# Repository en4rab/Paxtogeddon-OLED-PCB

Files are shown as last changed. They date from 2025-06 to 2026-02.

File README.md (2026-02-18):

# Paxtogeddon-OLED-PCB
### Hardware files for the Paxtogeddon reader with OLED display

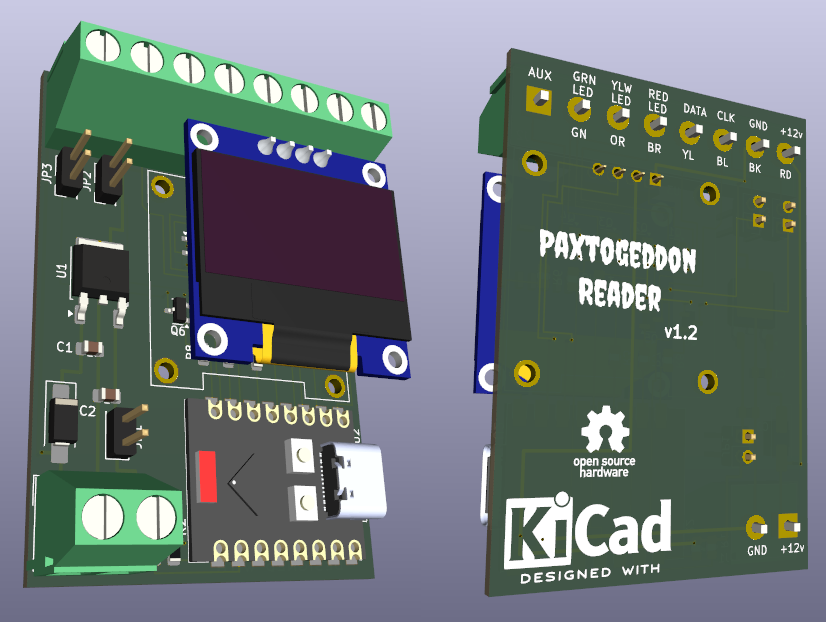
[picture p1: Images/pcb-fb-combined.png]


### kicad

The kicad directory contains the kicad project files to make a PCB for the Paxtogeddon reader. This was a project to learn Kicad and PCB design so set your expectations accordingly! If you just want to make one Paxtogeddon reader to use then you might find using 00Waz's [protoboard design](https://github.com/00Waz/Paxtogeddon-Reader) quicker and easier than ordering pcb's and smt parts from China.

### gerbers

The gerbers directory contains the gerbers for the v1.2 board and a zip file paxtogeddon-gerbers_v1_2.zip which is the zip file uploaded to JLC for manufacture of the PCB's. 

### case

The case directory contains the STL files and parts list for the 3D printed case to suit an Anker 525, 325 or 313 power bank.

### Firmware

This uses mostly the same code written by Daniel as the [board by 00Waz](https://github.com/00Waz/Paxtogeddon-Reader) with some additions to write to an OLED display. However the pin assignments are different and the pins to playback a card are now the same as those used to sniff so the associated headers and transistors can be left off. If this ever gets another revision of the pcb they will be removed. The PaxtogeddonReaderV1 directory contains the first attempt at adding an OLED, the additions were done by en4rab so any mistakes and poor code are my fault and not Daniels!  
[PaxtogeddonReaderV2.2](firmware/PaxtogeddonReaderV2_2) contains Daniel's improved version 2.2 code which supports both this PCB version and the protoboard design by Waz. It uses custom cards to configure the reader. Information on how to rewrite Paxton cards to use as the config cards can be found in [MAKE-CARDS.md](firmware/MAKE-CARDS.md)
This firmware now supports a second esp module connected to the paxtogeddon aux pin to trigger a cheap fitness band to vibrate when a card is read and new with v2.2 support for the paxton hand free interface and hands free fobs.

### Schematic

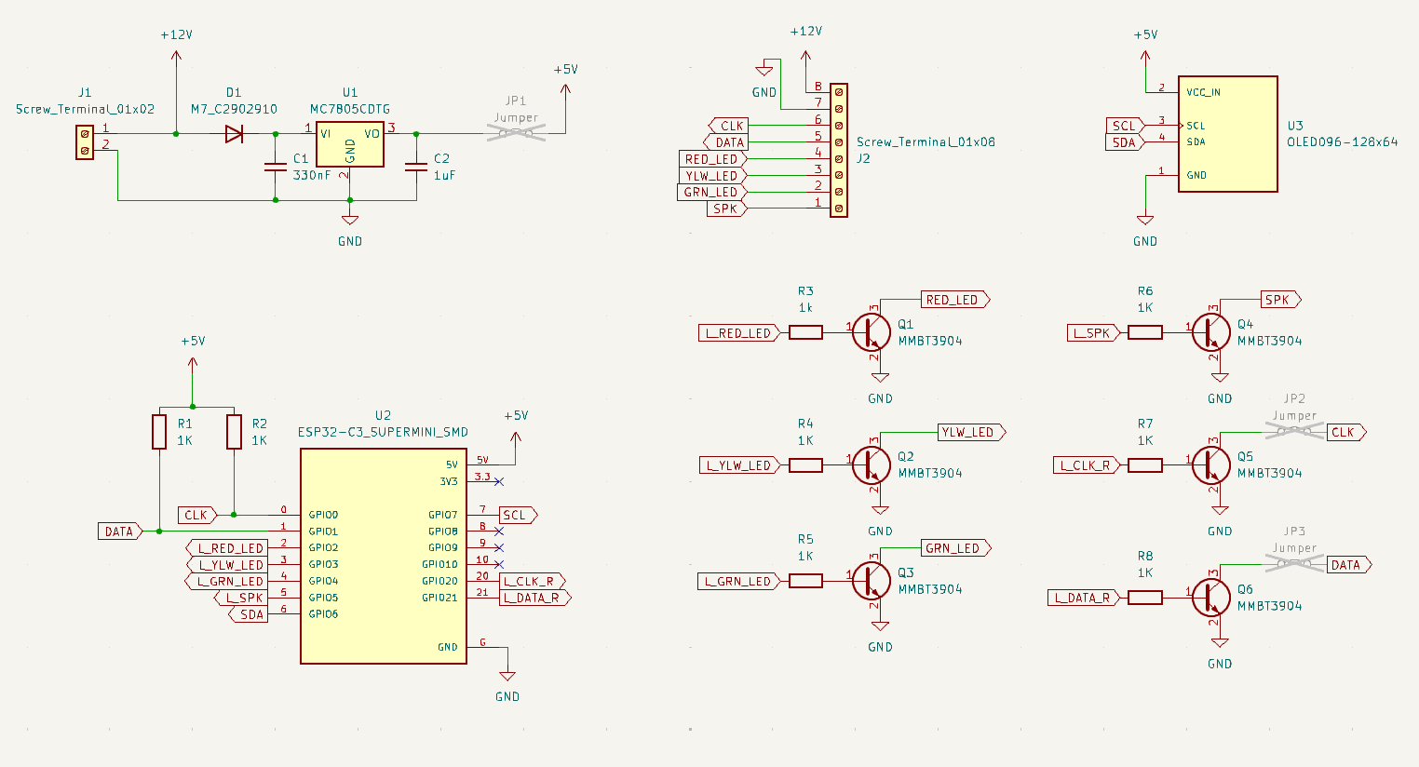
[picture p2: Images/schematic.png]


### Building the PCB
#### Assembly

Assembly is fairly straightforward. When soldering the 4 pin female header for the OLED it is easier to align it if you attach the brass standoffs to an OLED, put the header on the OLED pins then use it as a jig to hold the header in position while you solder it.

The jumper JP1 was for development to allow the 5v to be separated from the ESP32 so the Paxton reader could be powered by 12v while the esp was powered by usb for debugging. In normal use it should be connected.

JP2 and JP3 were to disconnect the card playback pins if that was not needed. In the latest firmware are unused and should be left disconnected.

Once the PCB has been soldered and cleaned use the Halnziye HY910 thermal glue to stick a small aluminium heatsink to the 7805 regulator. Initial tests without a heatsink had the regulator at about 89C adding a small heatsink lowered this to about 75C its a bit of a bodge but it seems to be working ok.

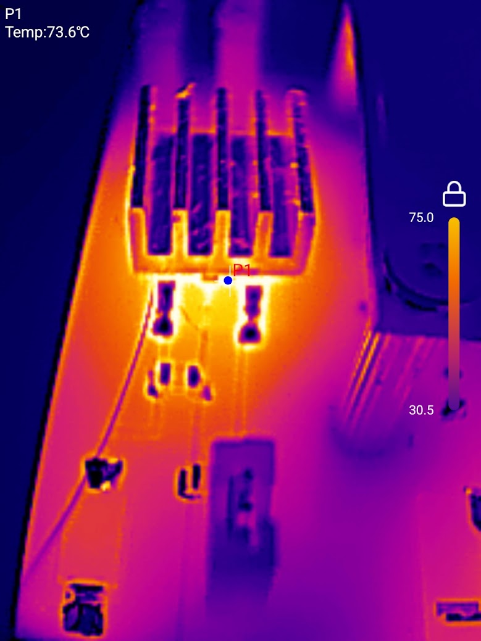
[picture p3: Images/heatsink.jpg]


#### Parts used 

This is a list of the parts used. They are not necessarily the best source and if you are being organised you could probably source everything in one order from Mouser/RS/Farnell but the links given are what was used. the 8 way screw terminal was 2x4 way terminals as they were easier to source.

| Reference | Value | Footprint | Link | Price |
| --- | --- | --- | --- | --- |
| C1 | 330nF 50v | 0805 | https://www.aliexpress.com/item/1005008635911110.html | £12.59 per 2000 |
| C2 | 1uF 16v | 0805 | https://www.aliexpress.com/item/33052613891.html | £0.88 per 100 |
| D1 | M7 (1N4007) | A-SMA | https://www.ebay.co.uk/itm/374441259098 | £4.66 per 100 |
| J1 | Screw_Terminal_01x02 | | https://www.aliexpress.com/item/1005003556955422.html | £4 per 50 |
| J2 | 2x Screw_Terminal_01x04 | | https://www.aliexpress.com/item/1005003556955422.html | £7.55 per 50 |
| JP1,JP2,JP3 | Jumper | | https://www.aliexpress.com/item/32853010777.html | £0.41 per 50 |
| Q1,Q2,Q3,<br />Q4,Q5,Q6 | MMBT3904 | SOT-23 | https://www.aliexpress.com/item/1005006991695298.html | £6.69 per 3000  |
| R1,R2,R3,R4,<br />R5,R6,R7,R8 | 1K 1/4W | 0805 | https://www.aliexpress.com/item/1005006786740896.html | £5.80 per 5000  |
| U1 | MC7805CDTG | TO-252-3  | https://www.aliexpress.com/item/1005007322548974.html | £1.16 per 5 |
| U2 | ESP32-C3 Supermini | | https://www.aliexpress.com/item/1005006056663228.html | £1.89 |
| U3 | OLED096-128x64 | | https://www.aliexpress.com/item/1005006700885056.html | £1.74 |
| | 4 pin socket female | | https://www.ebay.co.uk/itm/192175350096 | £3.89 per 100 |
| | Heatsink | 9x9x5mm | https://www.aliexpress.com/item/1005004453446730.html | £4.59 per 50 |
| | Halnziye HY910<br />Thermal glue | 5g | https://www.ebay.co.uk/itm/256626403139 | £2.75 |
| | 11mm M2 brass standoffs and M2 screws to mount the OLED are listed with the case hardware in the case directory | | | |

> [!CAUTION]
> The ESP32 supermini module has a near identical clone that is badly made and has problems with the wifi, this site describes the issue and how to spot the bad boards [https://roryhay.es/blog/esp32-c3-super-mini-flaw](https://roryhay.es/blog/esp32-c3-super-mini-flaw) TL;DR avoid the boards with "mouse bites" to separate the boards. If you do get a bad board and wifi doesn't work one test board worked better with a small blob of blu-tak stuck on the antenna simulating a finger touching the antenna. Guess how I figured that one out 🤣

> [!WARNING]  
> 0.96" OLED modules come in at least 4 different variants the most significant difference being the order of the pins. This board uses a 4 pin module with GND on the left most pin. They also differ in size and hole spacing. look for a seller showing a board with GME12864-11-12-13 on the back as shown.
>
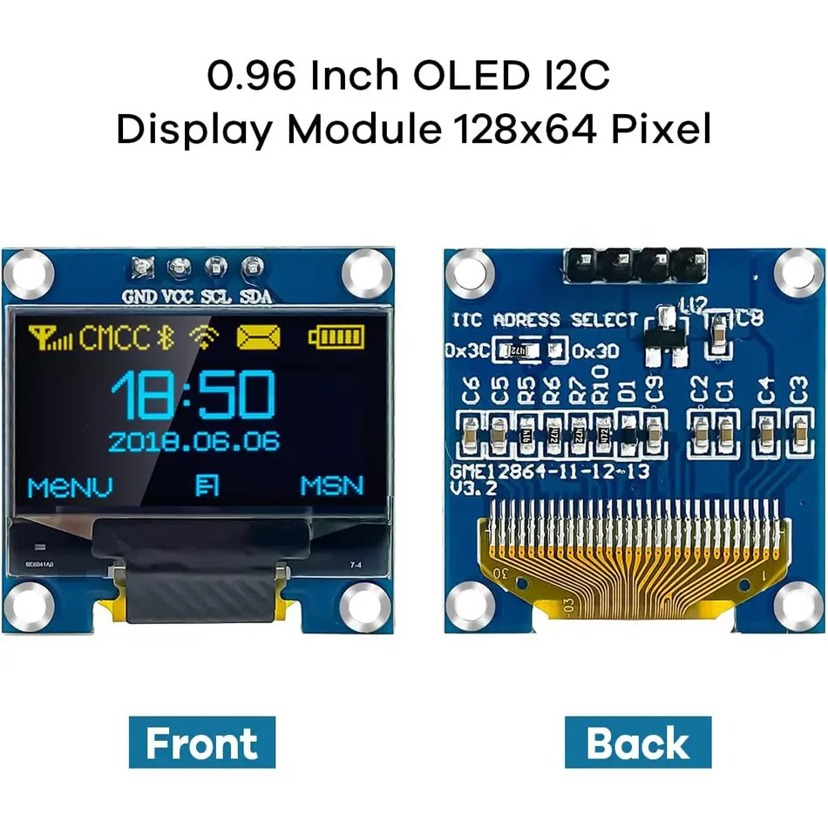
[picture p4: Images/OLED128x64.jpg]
>   

#### Errata

The latest version of the firmware being developed handles playback differently and doesn't use separate pins. This board used GPIO 20 and 21 for playback and jumpers JP2 and JP3 were to physically disconnect the lines if you didn't want to be able to playback cards. As playback is now done with the same pins as reading they are not used and can be left disconnected.

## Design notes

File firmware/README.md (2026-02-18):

## Firmware

This directory contains Daniels Paxtogeddon reader firmware.

PaxtogeddonReaderV2_2 is the current firmware and has the following features:

#### Function cards

You can now use a selection of function cards to do some nice stuff like:

* Display "TEST CARD" for use in the field as initial test to ensure everything is working before you head out
  * Card number - 99999999
* Revert to defaults if you forget your password for the wifi, but it wont clear the log!
  * Card number - 99999998
* Connects to configured AP instead of acting as AP
  * Card number - 99999997
* Display AP info on connected OLED screen in case you forget it
  * Card number - 99999996

For more info on creating these cards see [MAKE-CARDS.md](MAKE-CARDS.md)

#### Settings menu

With this version you can also configure it from the web GUI without the need to reflash it every time you want to change the SSID, change the IP, or change the refresh timer.
It also has a captive portal for when you connect to the SSID on a phone it loads automatically for quickly accessing the web GUI.

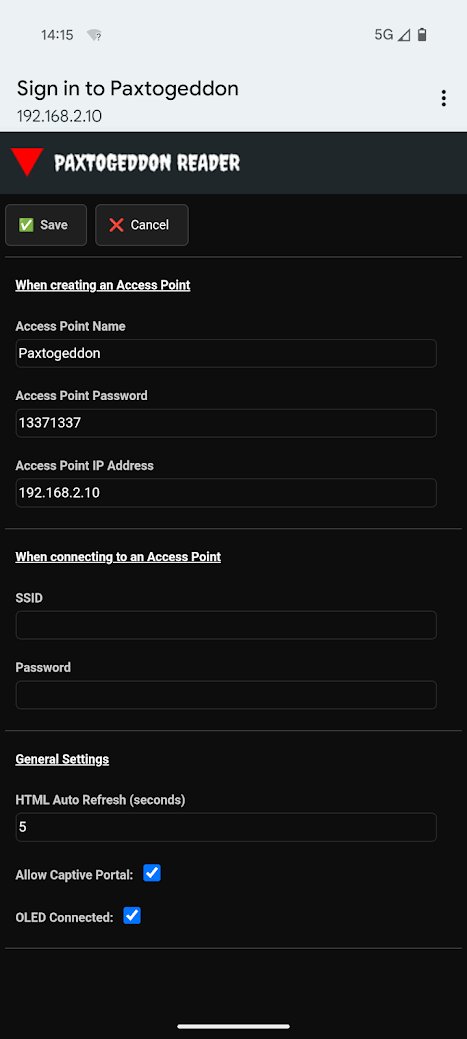
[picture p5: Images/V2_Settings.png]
V2 Settings Page


#### Send card number

Unlike V1, the transmission pins are the same as the capture pins for retransmission of data if connected inline with a reader.
You can also send a specific number direct from the web GUI if you just want to type one in. This will calculate the CLK/Data and send over the transmission pins.

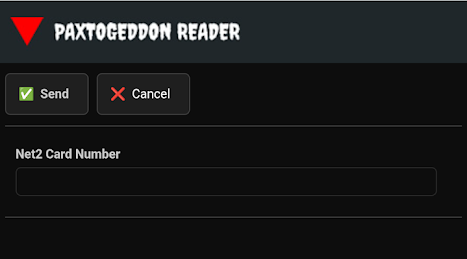
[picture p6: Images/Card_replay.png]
Send Card Number


#### Smart Watch Notifications

Nice little hook into a smart watch, so you get live notifications when a read is gained, so you know when you can do a happy root dance (while being hidden).

Another ESP32 board is needed, as it wont all fit onto to the one now, its getting a bit big and the supermini only has one core.
It requires a connection from the aux pin of the paxtogeddon to the second esp to trigger the second esp when a card is read.

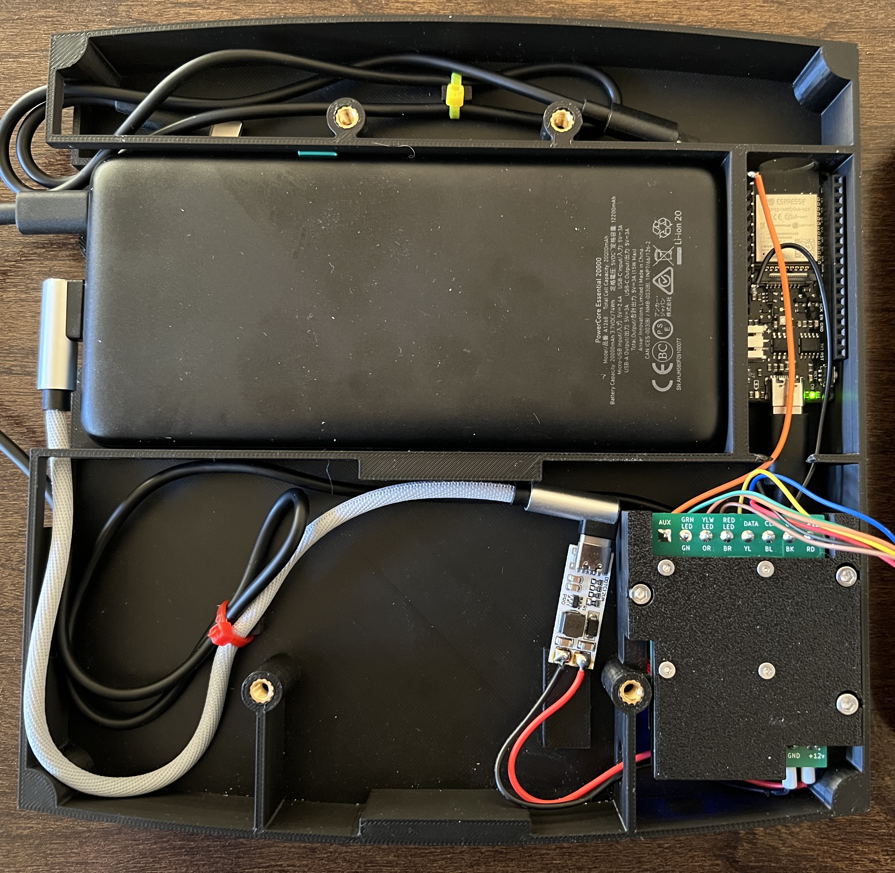
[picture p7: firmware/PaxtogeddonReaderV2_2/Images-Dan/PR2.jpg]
Kit layout


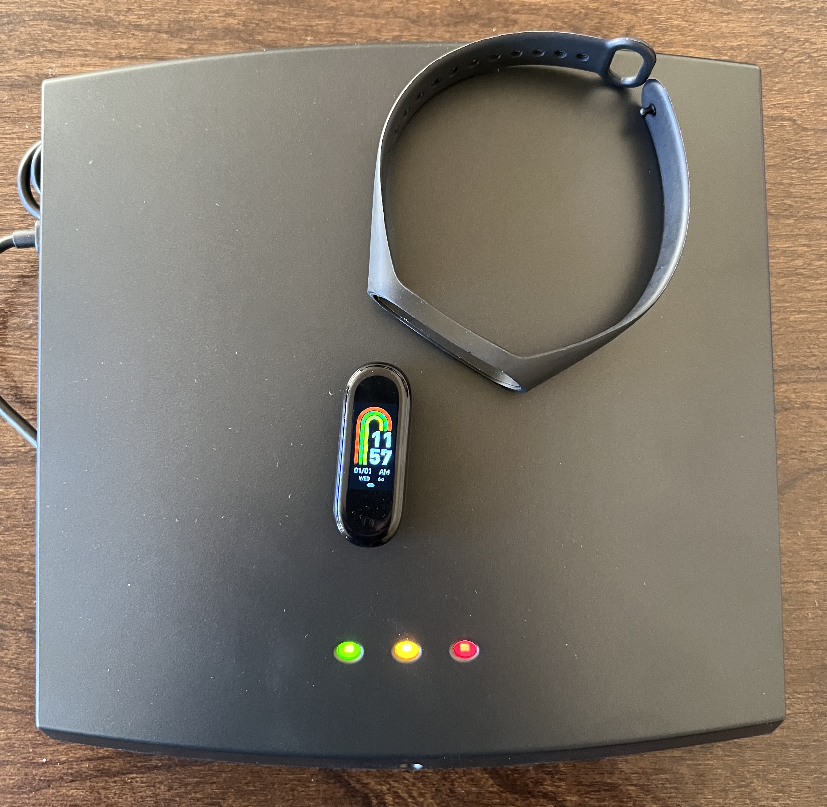
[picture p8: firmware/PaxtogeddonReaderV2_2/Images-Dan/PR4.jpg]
Smart Watch


It now hooks into a FitPro M4/M5/M6, super cheap on Amazon :)

#### Support for long range reader and hands free fob

Version 2.2 brings support for the Paxton 
[hands free interface](https://www.paxton-access.com/products/proximity-handsfree-interface-with-plastic-housing/) 
and [hands free fob](https://www.paxton-access.com/products/net2-hands-free-keyfob/) 
while these seem to be rare, if you wish to you can now wire in the hands free interface 
between the reader and the paxtogeddon board and capture the credentials from hands free fobs at a greater distance.
Paxton documentation suggests up to 2m for an NT200. Fitting this in the current reader case does require cutting 
one of the screw posts out to make room.  
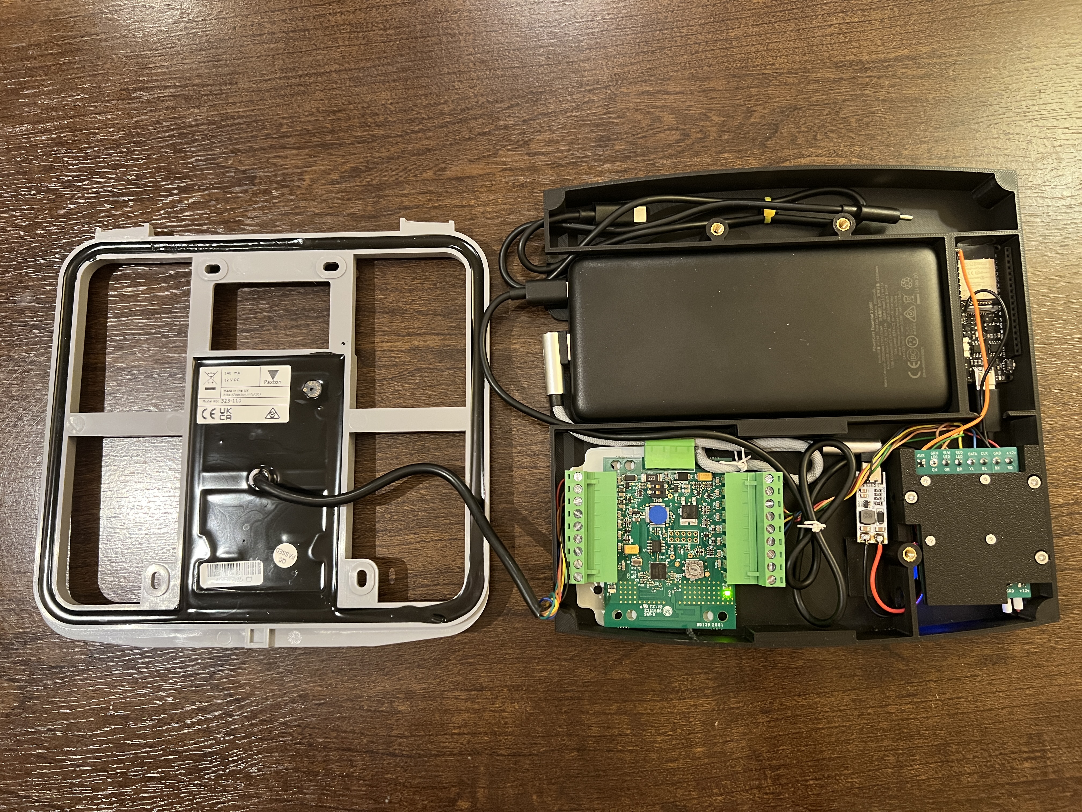
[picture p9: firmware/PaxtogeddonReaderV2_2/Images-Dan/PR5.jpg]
Making it fit


#### Companion App

There's a companion app to run on a windows host to make cloning cards easier, as it will send the commands directly from the web gui straight to your proxmark via the proxspace container app set up on Windows ([Proxspace Github](https://github.com/Gator96100/ProxSpace))

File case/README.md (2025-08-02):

# Paxtogeddon-OLED-Case
### STL files for the Paxtogeddon reader with OLED case to fit Anker 525/325/313 power bank

The original case design was by 00Waz and this version was edited by en4rab to fit an Anker 325 or 525 power bank and pcb reader, any problems with it are en4rab's fault. 
To make a reader you need "Paxtogeddon-bracket.stl" and "Paxtogeddon-case-anker.stl" 

If you don’t have a P200 reader but want to make a demo device with a different model of reader there is "Paxtogeddon-case-coverplate.stl" which will adapt a P75 or P50 reader to fit on the case.

To use the smaller Anker 313 powerbank print "Paxtogeddon-case-infill.stl" and slide this into the hole for the powerbank to resize it.

This is a list of the misc hardware used to mount the pcb and reader into case. The URL's are not necessarily the best place to get the parts you may be able to get stuff cheaper but these are the listings used to get parts from:

| Qty  | Desc | Source | Price |
| ---- | --- | --- | --- |
| 4 | M2 x 6 CSK to mount the OLED | https://www.aliexpress.com/item/32804364820.html | £1.24 per 50  |
| 4 | M2 x 10 CSK to mount the pcb to the carrier | https://www.aliexpress.com/item/32804364820.html | £2.01 per 50  |
| 4 | M2 x 11mm brass standoffs | https://www.aliexpress.com/item/1005006412726013.html | £2.84 per 100 |
| 4 | M4 x 8 x 6OD Heat-Set Threaded Inserts | https://www.aliexpress.com/item/1005006798286851.html | £5.31 per 100 |
| 3 | M3 x 5 x 5OD Heat-Set Threaded Inserts | https://www.aliexpress.com/item/1005006798286851.html | £2.74 per 100 |
| 4 | M4 x 10 Cap head | https://www.aliexpress.com/item/33008696963.html | £5.89 per 100 |
| 3 | M3 x 10 Cap head | https://www.aliexpress.com/item/33008696963.html | £3.34 per 100 |
| 1 | TECHGEAR USB Type C Cable 30cm short 90 Degree Right Angle | https://www.amazon.co.uk/TECHGEAR-Reversible-Compatible-Samsung-OnePlus/dp/B07SSSGLJV | £3.95 |
| 1 | USB-C to 12v boost converter | https://www.aliexpress.com/item/4000926897096.html | £1.47 |

> [!WARNING]  
> Since designing this Anker appear to have discontinued the 525 power bank (A1287).
> An alternative USB 5v to 12v boost converter module was tested instead of the power delivery module which worked well so a non power delivery powerbank like the Anker 325 (A1268) which is the same size can be used. The slightly smaller 313 (A1229) can also work with a 3d printed insert to make the battery slot smaller. 
> As the boost converter module works the original power delivery module is no longer recommended and has been replaced in the parts list with the boost converter.

| Qty  | Desc | Source | Price |
| ---- | --- | --- | ----- |
| 1 | Anker 525 Power Bank (PowerCore 20K) | https://www.anker.com/uk/products/a1287 | £30 |
| 1 | Anker 325 Power Bank (PowerCore 20K) | https://www.anker.com/uk/products/a1268 | £30 |
| 1 | Anker 313 Power Bank (PowerCore 10K) | https://www.anker.com/uk/products/a1229 | £18 |

#### Assembly instructions

Build and program a Paxtogeddon reader PCB.  
Print the bracket and the case.  
Using a soldering iron insert the heatset inserts for the reader mounting (M4) and the PCB bracket (M3)  
Using 4 M2 x 10 CSK screws screw the PCB into the bracket.  

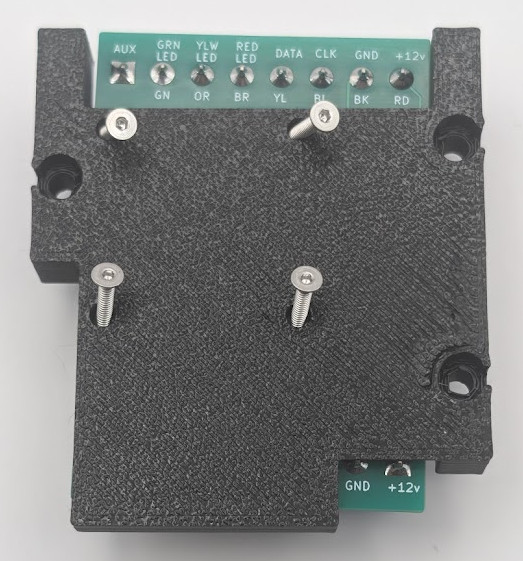
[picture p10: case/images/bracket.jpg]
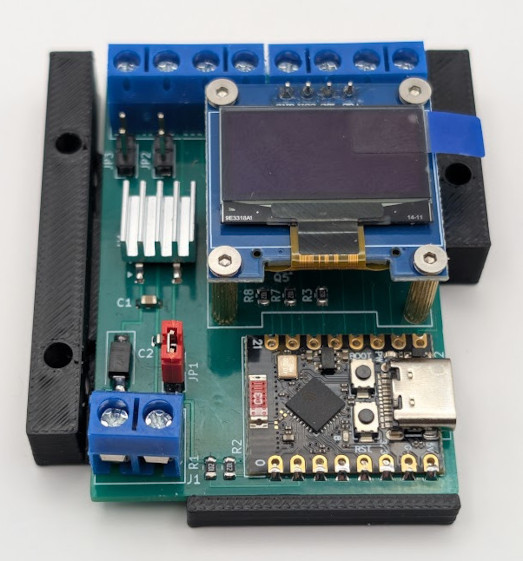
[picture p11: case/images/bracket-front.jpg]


Cut the P200 reader cable to length and wire it to the paxtogeddon PCB. Its probably not best practice but I terminated the P200 wires by stripping the wire folding the end back over the insulation then crimping a bootlace ferrule to the end of the wire.

Solder wires to the USB-C to 12v power supply module, trim the wires to length, test it works and then superglue the board to the raised plinth next to where the paxtogeddon PCB is mounted.
Connect the wires from the 12v module paying attention to polarity.
Mount the bracket into the case using 3x M3x10 Cap head screws.

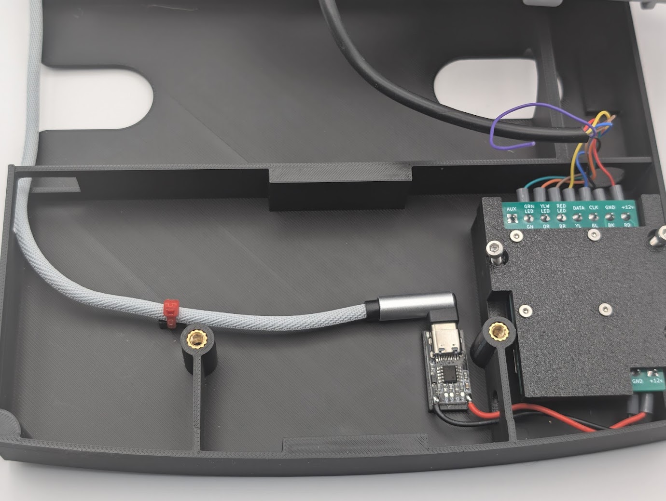
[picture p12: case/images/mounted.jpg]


Insert the USB C cable into the 12v module and cable tie it securely to the cable tie loop, then pass the USB-A end through the slot in the case.

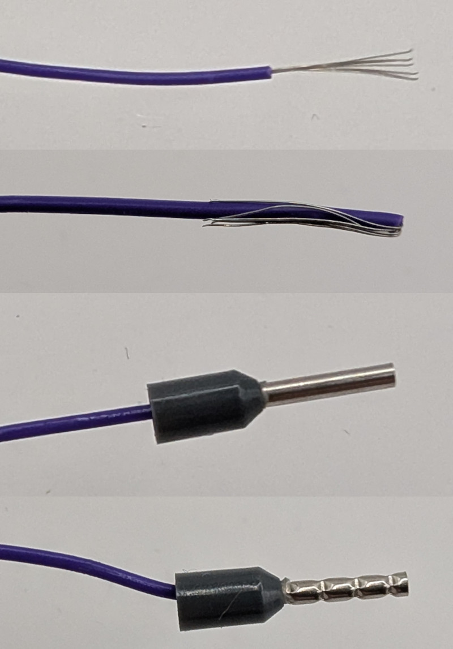
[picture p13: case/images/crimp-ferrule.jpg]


While it is not how ferrules are supposed to be used, the wires from the P200 are quite thin so to terminate them in a manner suitable for screw terminals the ends of the wires were stripped. The stripped wire was then folded back over the insulation and then crimped in a ferrule. 

Screw the P200 reader to the case using 4x  M4x10 Cap head screws.

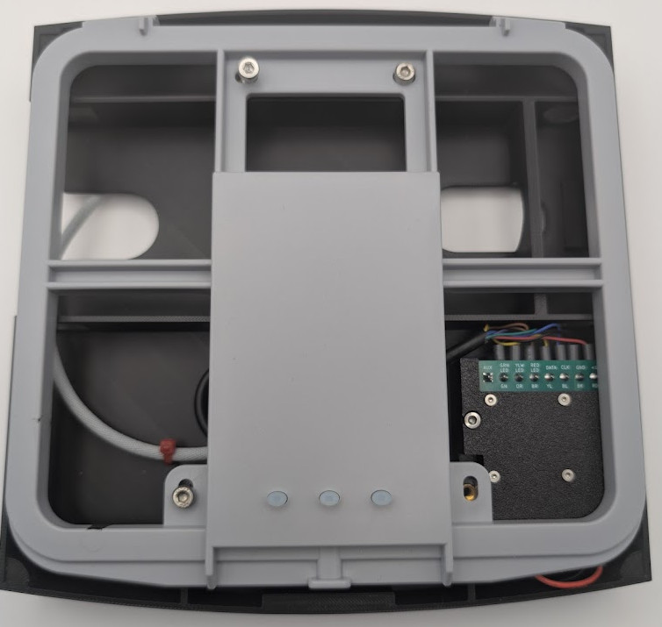
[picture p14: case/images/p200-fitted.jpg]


Fit the P200 cover and its retaining screw then slide the Anker power bank into the side of the case.

To use the reader insert the USB-A connector into the power bank and it should power up automatically.

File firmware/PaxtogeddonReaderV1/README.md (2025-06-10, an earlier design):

### Overview

The Paxtogeddon reader is source code to create a weaponised reader to target Paxton Net2 and Switch2 tokens.

Features:

* CLK/DATA decoding straight off the back of the reader
* Paxton auth token decoding
  * Also determines if its was a Net2 or Switch2 token, and even the colour of the fob!
* Persistent log saving on SPIFFS
* Wifi AP ect for in the field shinanigans

### Quote from the codes main developer

```
"Anyone can share it mate, do whatever you want with it. 
Stick it on your own GitHub, I don’t mind at all. 👍"
```

Note I was not the main writer of this code, but Dan couldn't be bothered to put it on GitHub because he not a hacker.

### Quote from En4rab

```
“I would have used my own code but it was shit and Daniel's is much better”
```

### Bill of materials

* See the main page for [hardware details](https://github.com/en4rab/Paxtogeddon-OLED-PCB/)

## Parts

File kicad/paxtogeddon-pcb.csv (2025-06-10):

Reference | Value | Datasheet | Footprint | Qty | DNP
C1 | 330nF | ~ | Capacitor_SMD:C_0805_2012Metric_Pad1.18x1.45mm_HandSolder | 1
C2 | 1uF | ~ | Capacitor_SMD:C_0805_2012Metric_Pad1.18x1.45mm_HandSolder | 1
D1 | M7_C2902910 | ~ | Diode_SMD:D_SMA_Handsoldering | 1
J1 | Screw_Terminal_01x02 | ~ | TerminalBlock_Altech:Altech_AK100_1x02_P5.00mm | 1
J2 | Screw_Terminal_01x08 | ~ | TerminalBlock_Altech:Altech_AK100_1x08_P5.00mm | 1
JP1,JP2,JP3 | Jumper | ~ | Connector_PinHeader_2.54mm:PinHeader_2x01_P2.54mm_Vertical | 3
Q1,Q2,Q3,Q4,Q5,Q6 | MMBT3904 | https://www.onsemi.com/pdf/datasheet/pzt3904-d.pdf | Package_TO_SOT_SMD:SOT-23 | 6
R1,R2,R3,R4,R5,R6,R7,R8 | 1K | ~ | Resistor_SMD:R_0805_2012Metric | 7
U1 | MC7805CDTG | https://www.onsemi.com/download/data-sheet/pdf/mc7800-d.pdf | Package_TO_SOT_SMD:TO-252-2 | 1
U2 | ESP32-C3_SUPERMINI_SMD |  | paxtogeddon:MODULE_ESP32-C3_SUPERMINI | 1
U3 | OLED096-128x64 | https://www.buydisplay.com/download/manual/ER-OLEDM0.96-1_Series_Datasheet.pdf | paxtogeddon:MODULE_ER-OLED096-I2C | 1

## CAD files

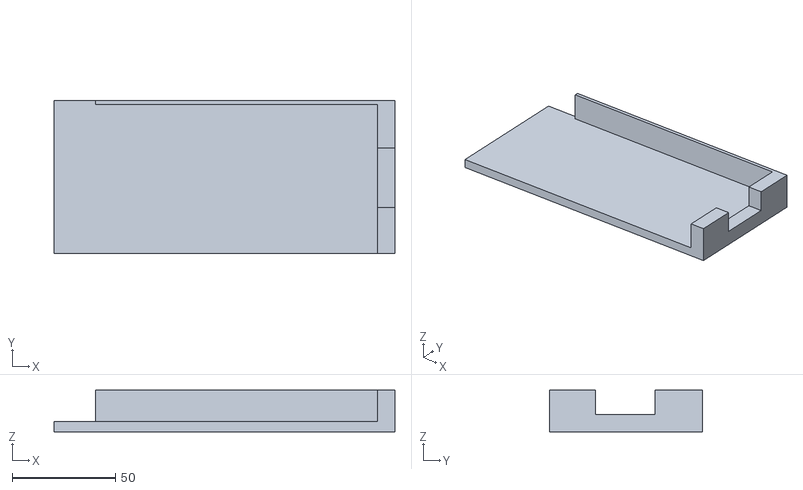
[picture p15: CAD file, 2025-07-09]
case/Paxtogeddon-case-infill.stl
165.0 x 74.0 x 20.1

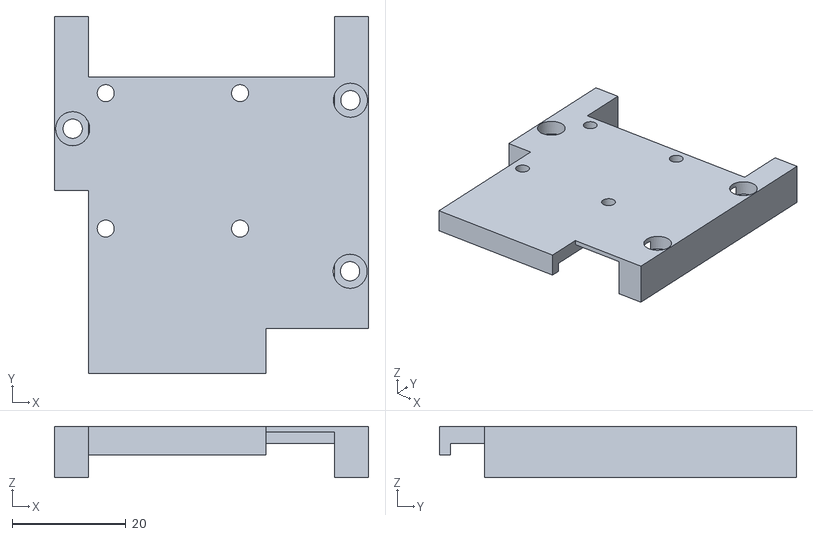
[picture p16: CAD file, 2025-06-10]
case/Paxtogeddon-case-bracket.stl
55.2 x 62.8 x 9.00

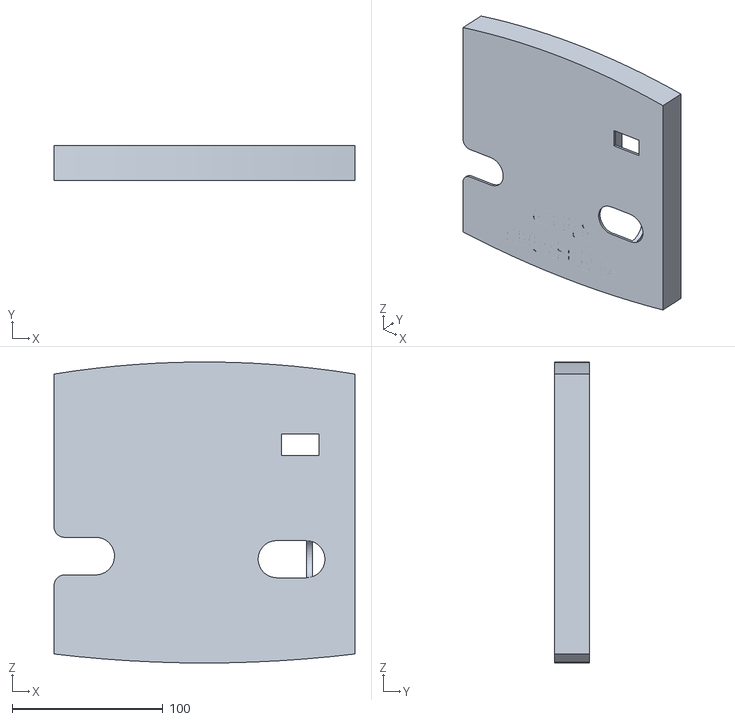
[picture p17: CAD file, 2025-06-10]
case/Paxtogeddon-case-anker.stl
200.0 x 23.1 x 200.0

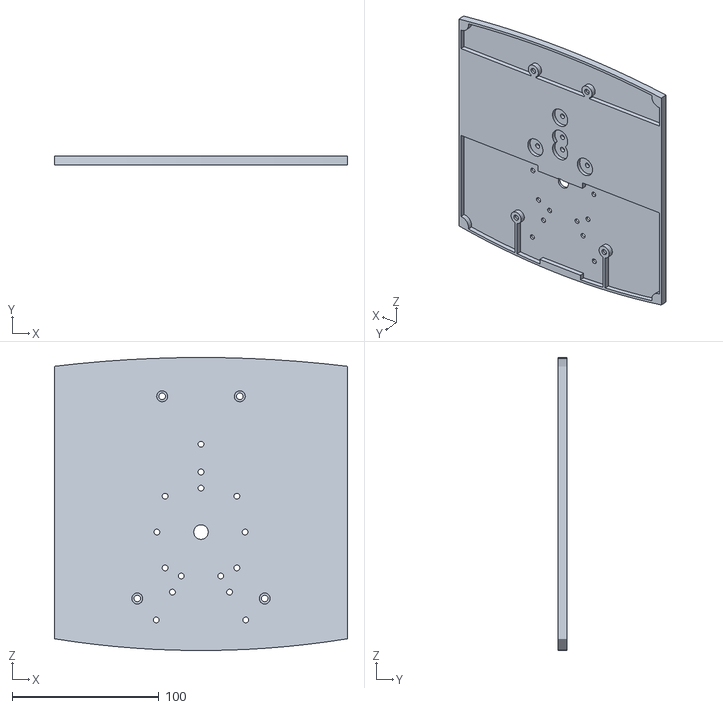
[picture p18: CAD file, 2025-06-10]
case/Paxtogeddon-case-coverplate.stl
200.0 x 6.00 x 200.0

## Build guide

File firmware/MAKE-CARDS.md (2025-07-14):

To configure the Paxtogeddon reader you will need to make a couple of config cards.

These are best made by rewriting some Paxton ISO cards. It is assumed you will have some spare as the making full use of the reader requires being able to clone cards. It is entirely possible to clone to a blank hitag2 cards by writing the appropriate password and configuration to it but writing those carries with it a risk of a bad write bricking the card. It is much easier to buy a pack of Paxton ISO cards from eBay and rewrite those.

#### Paxton function cards

Paxton readers made after 2015 will respond to config cards for the first 2 minutes after power on. These cards allow you to configure options mostly relating to the switch2 system but of interest to this application are "Silent Operation" and "Backlight Dimmer"

These two cards will allow you to turn off the beep when a card is scanned and adjust the brightness of the led's on the front of the reader. You can either buy these cards or rewrite a Paxton card.  

To convert a normal Paxton card into a Silent operation card use the following commands on your proxmark3:  

```
lf hitag wrbl --ht2 -k BDF5E846 -p 4 -d 84030810  
lf hitag wrbl --ht2 -k BDF5E846 -p 5 -d AE441204  
lf hitag wrbl --ht2 -k BDF5E846 -p 6 -d ADAB0840  
lf hitag wrbl --ht2 -k BDF5E846 -p 7 -d 08610084
```  

Present this card to the reader within 2 mins of power on and it will toggle beeping when reading a card. The reader will still beep once at power on.  

To change a Paxton card to a backlight dimmer card:  
```
lf hitag wrbl --ht2 -k BDF5E846 -p 4 -d 840309C0  
lf hitag wrbl --ht2 -k BDF5E846 -p 5 -d B06A7A88  
lf hitag wrbl --ht2 -k BDF5E846 -p 6 -d 3CF27840  
lf hitag wrbl --ht2 -k BDF5E846 -p 7 -d 09216084
```  

Each time you present the card it changes the LED brightness very roughly like 100% > 75% > 50% > 25% > off > 100%

If you don't want the LED's active they can always be left disconnected but this gives the option of them to be working but dimmed so they wont show through a bag.

#### Paxtogeddon function cards

The paxtogeddon code looks for Paxton cards with specific numbers in order to trigger specific functions.

The proxmark commands below are assuming you are changing the number of an already valid Net2 card if you are writing it to a blank hitag2 you would need to program the card as a Paxton card and write blocks 6 and 7 too. 

| Number | Function |
| --- | --- |
| 99999999 | Test card (will be logged as "Test") |
| 99999998 | Defaults the settings and Reboots the ESP32 whilst retaining the log |
| 99999997 | Reboots the ESP32 and connects to an access point if SSID and PW are set |
| 99999996 | Shows AP info on the OLED if the OLED is set as connected |

##### 99999999 Test Card

```
lf hitag wrbl --ht2 -k BDF5E846 -p 4 -d CE739CE4  
lf hitag wrbl --ht2 -k BDF5E846 -p 5 -d CE7F0006
```

##### 99999998 Reset to Defaults

```
lf hitag wrbl --ht2 -k BDF5E846 -p 4 -d CE739CE4  
lf hitag wrbl --ht2 -k BDF5E846 -p 5 -d CA3F0006
```

##### 99999997 Connect to AP

```
lf hitag wrbl --ht2 -k BDF5E846 -p 4 -d CE739CE4  
lf hitag wrbl --ht2 -k BDF5E846 -p 5 -d C9FF0006
```

##### 99999996 Show AP info

```
lf hitag wrbl --ht2 -k BDF5E846 -p 4 -d CE739CE4  
lf hitag wrbl --ht2 -k BDF5E846 -p 5 -d CDBF0006
```

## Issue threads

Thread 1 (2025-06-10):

Offer to Help with Hardware Implementation and Manufacturing

eqycc, 2025-06-10:
Hi Robin,

I hope you're doing well!

I came across your project and really admire the work you've done. I have experience in hardware development and would love to help with the physical implementation — like sourcing parts, PCB assembly, soldering, and even shipping the completed prototype back to you.

If you have any upcoming builds or hardware iterations, I’d be happy to take that part off your hands so you can focus more on design and software.

Let me know if that’s something you’d find helpful!

Best regards,
Javon

Closed 2025-06-10.

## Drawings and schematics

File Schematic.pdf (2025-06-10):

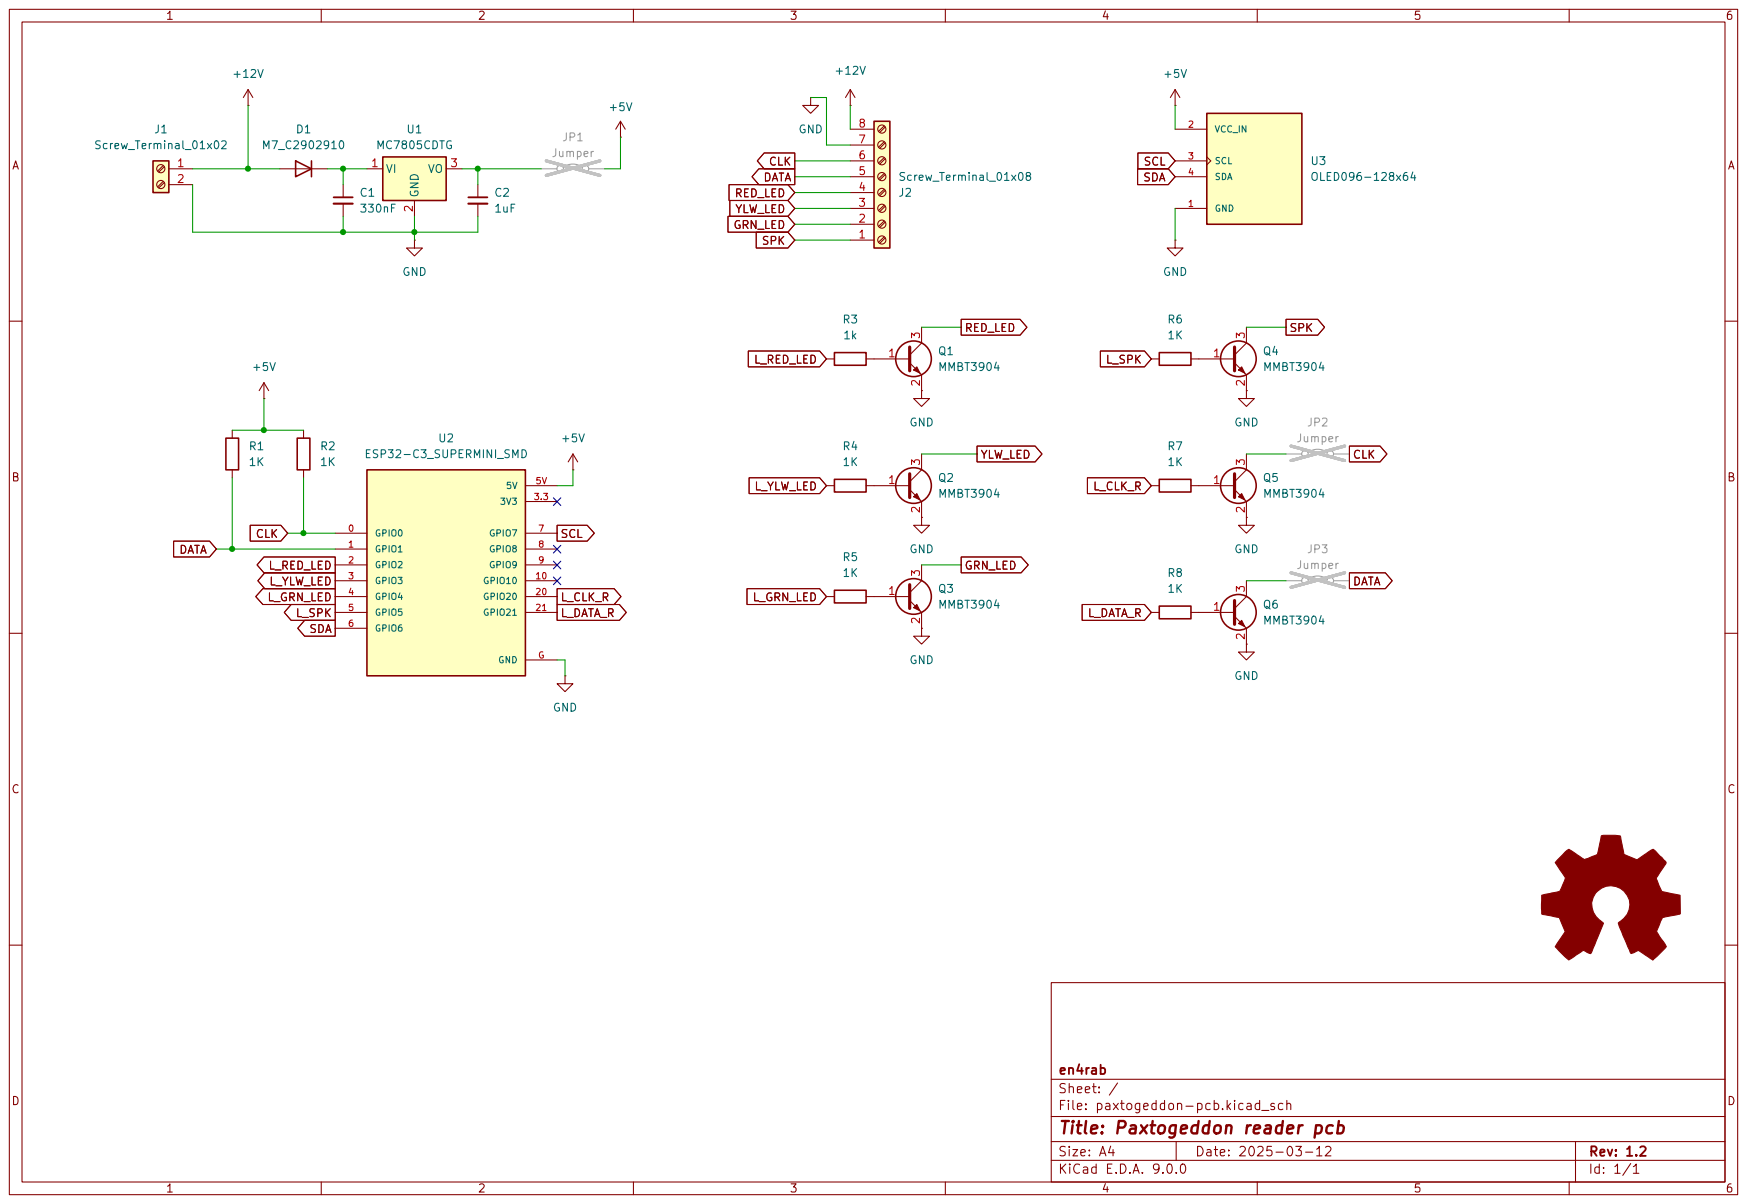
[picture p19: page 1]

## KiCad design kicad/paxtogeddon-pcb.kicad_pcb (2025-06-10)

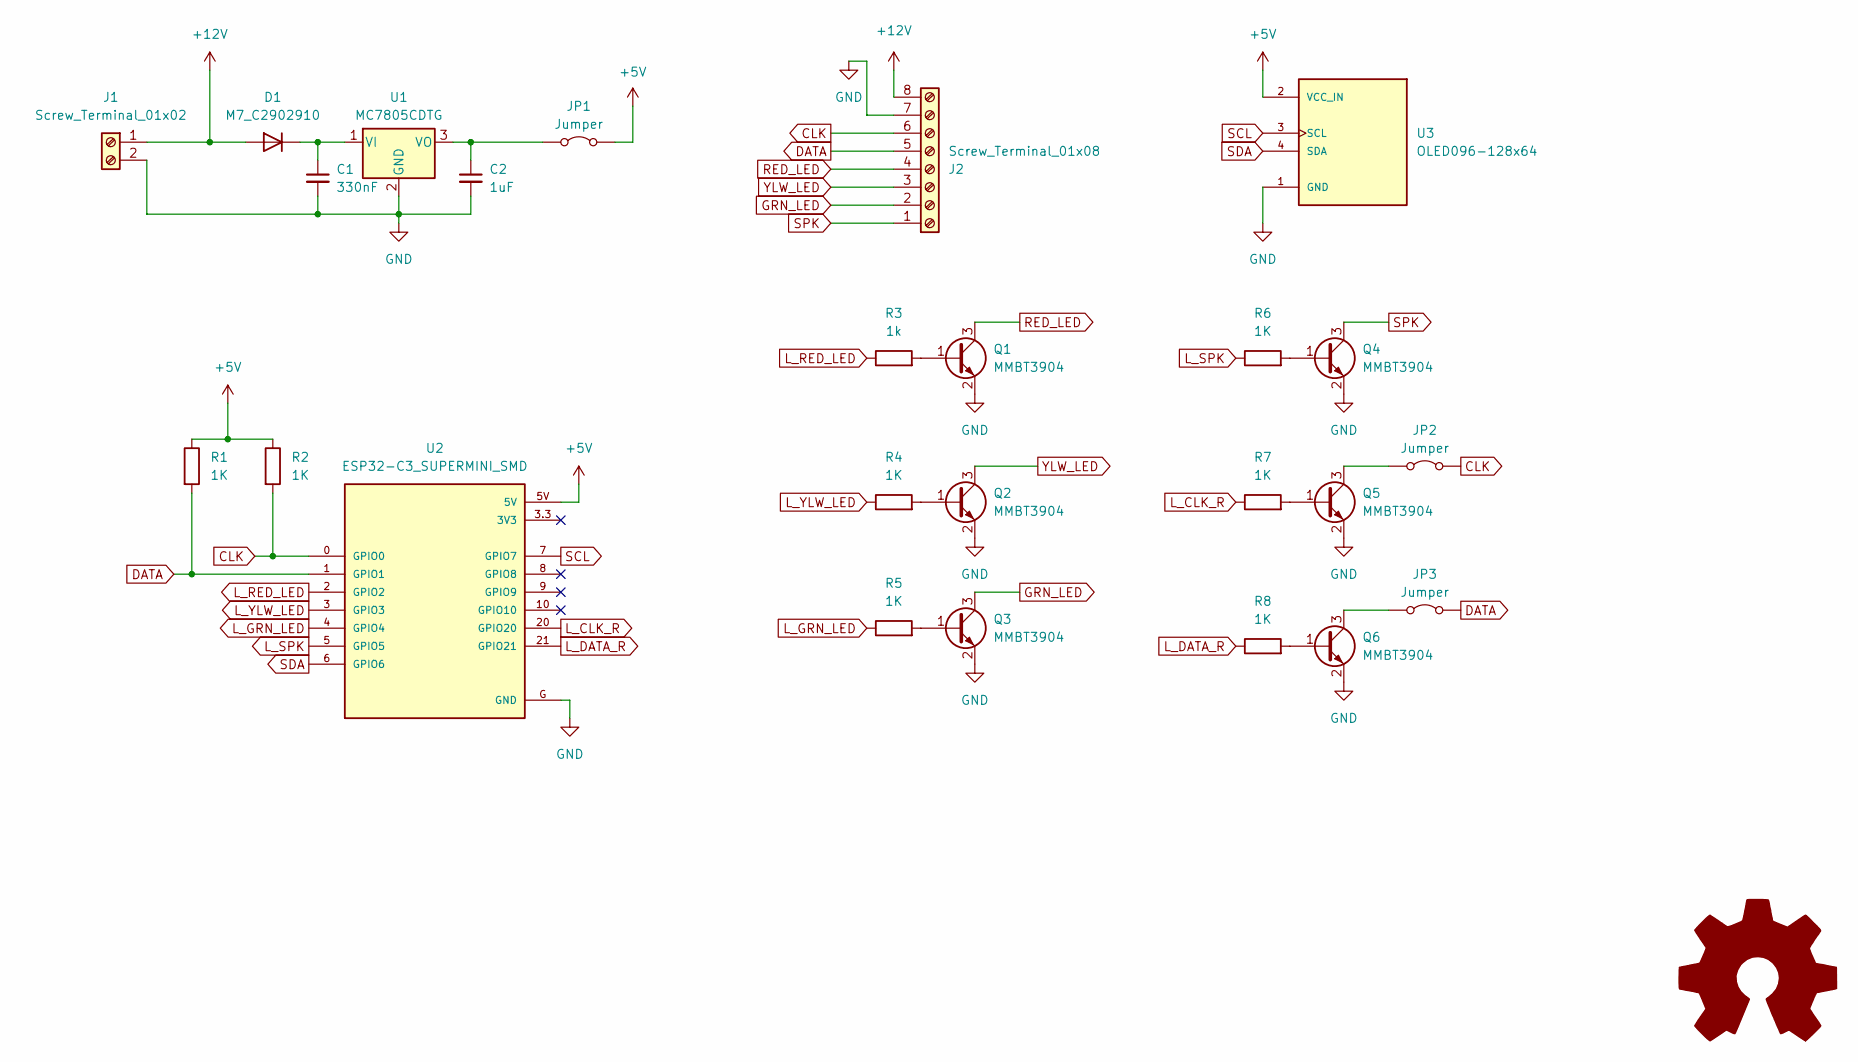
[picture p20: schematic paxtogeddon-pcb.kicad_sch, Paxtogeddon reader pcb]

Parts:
C1: 330nF; C_0805_2012Metric_Pad1.18x1.45mm_HandSolder
C2: 1uF; C_0805_2012Metric_Pad1.18x1.45mm_HandSolder
D1: M7_C2902910; D_SMA_Handsoldering
J1: Screw_Terminal_01x02; Altech_AK100_1x02_P5.00mm
J2: Screw_Terminal_01x08; Altech_AK100_1x08_P5.00mm
JP1, JP2, JP3: Jumper; PinHeader_2x01_P2.54mm_Vertical
Q1, Q2, Q3, Q4, Q5, Q6: MMBT3904; SOT-23
R1, R2, R4, R5, R6, R7, R8: 1K; R_0805_2012Metric
R3: 1k; R_0805_2012Metric
U1: MC7805CDTG; TO-252-2
U2: ESP32-C3_SUPERMINI_SMD; MODULE_ESP32-C3_SUPERMINI
U3: OLED096-128x64; MODULE_ER-OLED096-I2C; PARTREV 2018-09-10

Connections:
+5V: JP1.2 (B), R1.1, R2.1, U2.5V, U3.2 (VCC_IN)
+12V: D1.2 (A), J1.1, J2.8
CLK: J2.6, JP2.2 (B), R2.2, U2.0 (GPIO0)
DATA: J2.5, JP3.2 (B), R1.2, U2.1 (GPIO1)
GND: C1.2, C2.2, J1.2, J2.7, Q1.2 (E), Q2.2 (E), Q3.2 (E), Q4.2 (E), Q5.2 (E), Q6.2 (E), U1.2 (GND), U2.G (GND), U3.1 (GND)
GRN_LED: J2.2, Q3.3 (C)
L_CLK_R: R7.1, U2.20 (GPIO20)
L_DATA_R: R8.1, U2.21 (GPIO21)
L_GRN_LED: R5.1, U2.4 (GPIO4)
L_RED_LED: R3.1, U2.2 (GPIO2)
L_SPK: R6.1, U2.5 (GPIO5)
L_YLW_LED: R4.1, U2.3 (GPIO3)
unnamed: C1.1, D1.1 (K), U1.1 (VI)
unnamed: C2.1, JP1.1 (A), U1.3 (VO)
unnamed: JP2.1 (A), Q5.3 (C)
unnamed: JP3.1 (A), Q6.3 (C)
unnamed: Q1.1 (B), R3.2
unnamed: Q2.1 (B), R4.2
unnamed: Q3.1 (B), R5.2
unnamed: Q4.1 (B), R6.2
unnamed: Q5.1 (B), R7.2
unnamed: Q6.1 (B), R8.2
RED_LED: J2.4, Q1.3 (C)
SCL: U2.7 (GPIO7), U3.3 (SCL)
SDA: U2.6 (GPIO6), U3.4 (SDA)
SPK: J2.1, Q4.3 (C)
YLW_LED: J2.3, Q2.3 (C)

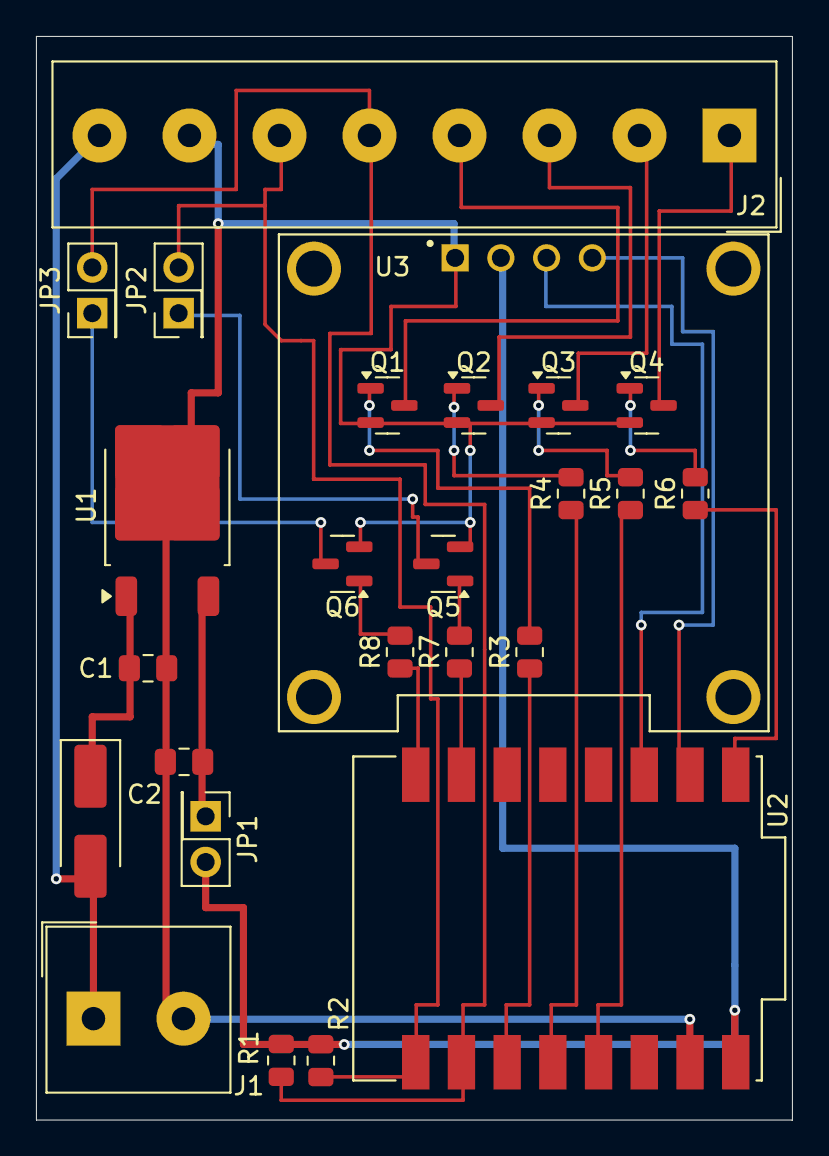
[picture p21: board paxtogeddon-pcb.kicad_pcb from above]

Board: 2 copper layers, 42.0 x 60.2 mm, 25 parts (0 on the bottom side), 27 nets.

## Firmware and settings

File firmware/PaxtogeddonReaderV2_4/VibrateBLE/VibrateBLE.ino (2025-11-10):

/*
__________                  __                           .___  .___             
\______   \_____  ___  ____/  |_  ____   ____   ____   __| _/__| _/____   ____  
 |     ___/\__  \ \  \/  /\   __\/  _ \ / ___\_/ __ \ / __ |/ __ |/  _ \ /    \ 
 |    |     / __ \_>    <  |  | (  <_> ) /_/  >  ___// /_/ / /_/ (  <_> )   |  \
 |____|    (____  /__/\_ \ |__|  \____/\___  / \___  >____ \____ |\____/|___|  /
                \/      \/            /_____/      \/     \/    \/           \/ 

Product Name:  Vibrate BLE for Paxtogeddon Reader
Version:       1.0
Build Date:    2025-11-02
Author:        Daniel Raines [ Dr0pR00t ]

Credit: Cardinal_Black (Original BLE lib/commands for FitPro M4/M5/M6)

Shopping links...
https://www.aliexpress.com/item/1005008971783153.html
https://www.aliexpress.com/item/1005009086572716.html

This code was tested using a FireBeetle 2 ESP32-E
Trigger pin and status LED pin can be adjusted in pr_settings.cpp
*/

#include <Arduino.h>
#include "pr_settings.h"
#include "pr_util.h"
#include "pr_ble.h"

void setup() {
  prUtil::SettingsInit();
  prUtil::GPIOInit();
  prBLE::FitProM4Init();
}

void loop() {
  if (prSettings::bleScanMode) {
    prBLE::ScanDevices();
  } else {
    prBLE::MaintainConnection();
  }
  prBLE::InputTriggerHandler();
}

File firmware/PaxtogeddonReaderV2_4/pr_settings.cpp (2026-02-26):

#include "pr_settings.h"

namespace prSettings {

//Product
const String VERSION_NUMBER = "2.4";
const String BUILD_DATE = "2026-02-25";

//OLED
const byte SCREEN_WIDTH = 128;     //OLED display width, in pixels
const byte SCREEN_HEIGHT = 64;     //OLED display height, in pixels
const byte OLED_RESET = -1;        //Reset pin (-1 if sharing Arduino reset pin)
const byte SCREEN_ADDRESS = 0x3C;  //0x3D for 128x64, 0x3C for 128x32 (see datasheet)

//Test Card - works as normal but will log the Type as "TEST CARD"
const String TEST_CARD = "99999999";

//Function Cards - these cards perform an action and are not logged
const String FC_DEFAULT = "99999998";        //Defaults the settings and Reboots the ESP32 whilst retaining the log
const String FC_CONNECT_TO_AP = "99999997";  //Reboots the ESP32 and connects to an access point rather than creating one, if SSID and PW are set
const String FC_SHOW_AP_INFO = "99999996";   //Shows AP info on the OLED if the OLED is set as connected



//PIN Assignments -------------------------------------------------------------------------------------------------------------------------

//!!! SELECT ONLY ONE !!! >>>

//#define GPIO_FIREBEETLE_2_ESP32_E_DEVT  //FireBeetle 2 ESP32-E (Dev Test) [ Dr0pR00t ] [ Daniel Raines                                  ]
//#define GPIO_ESP32_C3_SUPER_MINI_DIY    //ESP32 C3 Super Mini  (DIY)      [ 00Waz    ] [ https://github.com/00Waz/Paxtogeddon-Reader    ]
#define GPIO_ESP32_C3_SUPER_MINI_PCB      //ESP32 C3 Super Mini  (PCB)      [ en4rab   ] [ https://github.com/en4rab/Paxtogeddon-OLED-PCB ]
//-----------------------------------------------------------------------------------------------------------------------------------------



#ifdef GPIO_FIREBEETLE_2_ESP32_E_DEVT
const byte HEARTBEAT_LED_PIN = 2;  //[ OUTPUT ] -> Built-in LED
const byte CLOCK_PIN = 16;         //[ INPUT  ] -> P50/P200 Clock
const byte DATA_PIN = 17;          //[ INPUT  ] -> P50/P200 Data
const byte NOT_USED_PIN_A = 4;     //[ OUTPUT ] -> NO LONGER USED - SENDS CLOCK/DATA ON SAME PINS
const byte NOT_USED_PIN_B = 12;    //[ OUTPUT ] -> NO LONGER USED - SENDS CLOCK/DATA ON SAME PINS
const byte GREEN_LED_PIN = 25;     //[ OUTPUT ] -> P50/P200 Green LED
const byte YELLOW_LED_PIN = 13;    //[ OUTPUT ] -> P50/P200 Yellow LED
const byte RED_LED_PIN = 26;       //[ OUTPUT ] -> P50/P200 Red LED
const byte EXT_PIN = 255;          //[ OUTPUT ] -> 255 = NOT USED
const byte OLED_SDA_PIN = 255;     //I2C Serial Data -> 255 = NOT USED
const byte OLED_SCL_PIN = 255;     //I2C Serial Clock -> 255 = NOT USED
#endif

#ifdef GPIO_ESP32_C3_SUPER_MINI_DIY
const byte HEARTBEAT_LED_PIN = 8;  //[ OUTPUT ] -> Built-in LED
const byte CLOCK_PIN = 3;          //[ INPUT  ] -> P50/P200 Clock
const byte DATA_PIN = 4;           //[ INPUT  ] -> P50/P200 Data
const byte NOT_USED_PIN_A = 5;     //[ OUTPUT ] -> NO LONGER USED - SENDS CLOCK/DATA ON SAME PINS
const byte NOT_USED_PIN_B = 6;     //[ OUTPUT ] -> NO LONGER USED - SENDS CLOCK/DATA ON SAME PINS
const byte GREEN_LED_PIN = 0;      //[ OUTPUT ] -> P50/P200 Green LED
const byte YELLOW_LED_PIN = 1;     //[ OUTPUT ] -> P50/P200 Yellow LED
const byte RED_LED_PIN = 2;        //[ OUTPUT ] -> P50/P200 Red LED
const byte EXT_PIN = 255;          //[ OUTPUT ] -> 255 = NOT USED
const byte OLED_SDA_PIN = 255;     //I2C Serial Data -> 255 = NOT USED
const byte OLED_SCL_PIN = 255;     //I2C Serial Clock -> 255 = NOT USED
#endif

#ifdef GPIO_ESP32_C3_SUPER_MINI_PCB
const byte HEARTBEAT_LED_PIN = 8;  //[ OUTPUT ] -> Built-in LED
const byte CLOCK_PIN = 0;          //[ INPUT  ] -> P50/P200 Clock
const byte DATA_PIN = 1;           //[ INPUT  ] -> P50/P200 Data
const byte NOT_USED_PIN_A = 20;    //[ OUTPUT ] -> NO LONGER USED - SENDS CLOCK/DATA ON SAME PINS
const byte NOT_USED_PIN_B = 21;    //[ OUTPUT ] -> NO LONGER USED - SENDS CLOCK/DATA ON SAME PINS
const byte GREEN_LED_PIN = 4;      //[ OUTPUT ] -> P50/P200 Green LED
const byte YELLOW_LED_PIN = 3;     //[ OUTPUT ] -> P50/P200 Yellow LED
const byte RED_LED_PIN = 2;        //[ OUTPUT ] -> P50/P200 Red LED
const byte EXT_PIN = 5;            //[ OUTPUT ] -> Pulse output when a card is both read and logged successfully
const byte OLED_SDA_PIN = 6;       //I2C Serial Data
const byte OLED_SCL_PIN = 7;       //I2C Serial Clock
#endif
//-----------------------------------------------------------------------------------------------------------------------------------------


//User Config Defaults - Set by HTML settings page
String apSSID = "Paxtogeddon";
String apPassword = "13371337";
IPAddress apIP(192, 168, 2, 10);
String wifiSSID = "";
String wifiPassword = "";
IPAddress wifiIP(0, 0, 0, 0);
bool allowCaptivePortal = true;
String webPollSeconds = "5";
#ifdef GPIO_FIREBEETLE_2_ESP32_E_DEVT
bool oledConnected = false;
#endif
#ifdef GPIO_ESP32_C3_SUPER_MINI_DIY
bool oledConnected = false;
#endif
#ifdef GPIO_ESP32_C3_SUPER_MINI_PCB
bool oledConnected = true;
#endif
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

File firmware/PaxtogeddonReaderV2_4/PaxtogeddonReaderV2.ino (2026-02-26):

/*
__________                  __                           .___  .___             
\______   \_____  ___  ____/  |_  ____   ____   ____   __| _/__| _/____   ____  
 |     ___/\__  \ \  \/  /\   __\/  _ \ / ___\_/ __ \ / __ |/ __ |/  _ \ /    \ 
 |    |     / __ \_>    <  |  | (  <_> ) /_/  >  ___// /_/ / /_/ (  <_> )   |  \
 |____|    (____  /__/\_ \ |__|  \____/\___  / \___  >____ \____ |\____/|___|  /
                \/      \/            /_____/      \/     \/    \/           \/ 

Product Name:  Paxtogeddon Reader
Version:       2.4
Build Date:    2026-02-25
Author:        Daniel Raines [ Dr0pR00t ]

Credit [ALL]: Moral support + just being an awesome dudes!
Credit [ALL]: The legends who know who they are, that are not listed below, at their request.

Credit: 00Waz (Original decode + code for SPIFFS + case) [ https://github.com/00Waz/Paxtogeddon-Reader ]
Credit: En4rab (Original port of doorsim into MicroPython + parity/LRC insights + captive portal + OLED) [ https://github.com/en4rab/Paxtogeddon-OLED-PCB ]
Credit: Cardinal_Black (Original BLE lib/commands for FitPro M4/M5/M6) > VibrateBLE.ino
Credit: Craigsblackie (ASCII art) [ https://github.com/craigsblackie ]

FireBeetle 2 ESP32-E -> Server Tasks > Core 0 | Arduino/Events > Core 1
ESP32 C3 Super Mini -> Only has a single core

Net2 fobs > 10 bit leadin > b > 8 digit no. > f > lrc > 10 bit leadout (75 bits)
Net2 Long Range > 10 bit leadin > b > 8 digit no. > d >  25 bits (we assume these are for battery level) > f > lrc > 10 bit leadout (105 bits)
Switch2 fobs > 10 bit leadin > b > 8 digit no. > d > 15 digits > d > 12 zeros > f > lrc > 10 bit leadout (220 bits)

Paxtogeddon Reader v3.0 will contain refactored code in pr_cardreader as there is too much duplicated code!
This was ported from v1.0 and was initially all about debug. Now we know it works, things can be cleaned up.

I'm also hoping to change the ESP32 currently used in the PCB version so the VibrateBLE code can be merged here.
This will allow for single firmware and no additional board when using BLE.

##################################################
You can define PIN Assignments in pr_settings.cpp
by simply uncommenting your desired board. 
Default is #define GPIO_ESP32_C3_SUPER_MINI_PCB
##################################################

*/

#include <Arduino.h>
#include "pr_settings.h"
#include "pr_util.h"
#include "pr_server.h"
#include "pr_html.h"
#include "pr_cardreader.h"

void setup() {
  prUtil::SettingsInit();
  prUtil::GPIOInit();
  prUtil::OLEDInit();
  prUtil::SPIFFSInit();
  prCardReader::CardReaderInit();
  prServer::ServerInit();
}

void loop() {
  prUtil::HeartBeat();
  prUtil::CheckReboot();
  prUtil::CheckTriggerBLEScan();
  prCardReader::ParseCard();
}

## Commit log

2025-06-10 Initial commit
    Initial commit
    [Paxtogeddon reader bracket.stl, Paxtogeddon reader case anker.stl, Paxtogeddon reader case coverplate.stl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]
2025-06-10 Add front view of bracket
    Add front view of bracket assembly
2025-06-10 Add warnings about ESP32 and OLED sourcing
2025-07-09 Add anker 313 infill STL
    Add STL for Anker 313 powerbank adapter
    [Paxtogeddon-case-anker.stl, Paxtogeddon-case-bracket.stl, Paxtogeddon-case-coverplate.stl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]
2025-11-10 Initial add of V2.1 firmware
    Add V2.1 of the firmware which adds support for vibrating a BLE band
    [PaxtogeddonReaderV2.ino, VibrateBLE.ino, pr_cardreader.cpp]
